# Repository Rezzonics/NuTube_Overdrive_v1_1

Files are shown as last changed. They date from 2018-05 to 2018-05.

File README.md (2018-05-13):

# NuTube_Overdrive_v1_1 (EAGLE 6.3.0)
NuTube Overdrive guitar pedal

Eagle CAD 6.3.0:
- Eagle CAD Schematics (.sch)
- Eagle CAD Layout (.brd)
- Bill of Materials (txt, csv, xlsx)
- Components library (.lbr)

FreeCAD 16.0:
 - 3D CAD NuTube Overdrive enclosure
 
A <a href="https://www.youtube.com/watch?v=pDtBdqI9vC8&list=PLVcOAdxtwYCBdqzgB6T4JSNhljZ__4p3t">guitar pedal test video Youtube playlist<a>

# Disclaimer:
This is just an amateur pedal with no intention for profit or to infringe any trademark.
Tube Screamer is a trademark of Hoshino Gakki Co.
This pedal is not for sale. If you want to buy a similar pedal I recommend you <a href="http://www.ibanez.com/products/u_effect_page18.php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">Ibanez NTS Screamer<a>

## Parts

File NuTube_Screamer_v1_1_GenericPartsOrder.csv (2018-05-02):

Part Number | Mfg Name | VID | Vendor Part Num | Description | Customer Ref | Part Value | Tol | Size | Qty-1 | Qty-5 | Qty-25 | Part References | Value | XX
CRCW06030000ZSTB | Vishay | ME | 71-CRCW0603000ZT-RT5 | Thick Film Resistors - SMD 0603 1/10watt ZEROohm Jumper | res013 | 0 | * | * | 2 | 10 | 50 | R13, R14 | 0R | X
ERJ-3EKF1001V | Panasonic | ME | 667-ERJ-3EKF1001V | Thick Film Resistors - SMD 0603 1Kohms 1% Tol | res018 | 1k | * | * | 7 | 35 | 175 | R5, R9, R16, R23, R25, R27, R33 | 1K | X
CR0603-FX-1004ELF | Bourns | ME | 652-CR0603FX-1004ELF | Thick Film Resistors - SMD 0603 1M 1% 1/10W | res003 | 1M | * | * | 7 | 35 | 175 | R3, R7, R8, R11, R24, R26, R31 | 1M | X
C1608X7R1V105K080AE | TDK | ME | 810-C1608X7R1V105KAE | CAP CER 1UF 35V 10% X7R 0603 | capcer067 | 1u | 10% | * | 8 | 40 | 200 | C3, C4, C5, C6, C7, C18, C19, C23 | 1u | X
RC0603FR-073K3L | Yageo | ME | 603-RC0603FR-073K3L | Thick Film Resistors - SMD 0603 3.3kohms 1% Tol | res139 | 3.3k | * | * | 1 | 5 | 25 | R28 | 3.3k | X
ERJ-3EKF4701V | Panasonic | ME | 667-ERJ-3EKF4701V | Thick Film Resistors - SMD 0603 4.7Kohms 1% Tol | res027 | 4.7k | * | * | 1 | 5 | 25 | R15 | 4.7k | X
C2012X5R1E475K125AB | TDK | ME | 810-C2012X5R1E475K | CAP CER 4.7uF 25volts X5R 10% 0805 | capcer006 | 4.7u | 10% | * | 2 | 10 | 50 | C21, C31 | 4.7u | X
ERJ-3EKF4701V | Panasonic | ME | 667-ERJ-3EKF4701V | Thick Film Resistors - SMD 0603 4.7Kohms 1% Tol | res027 | 4.7k | * | * | 1 | 5 | 25 | R35 | 4k7 | X
CR0603-FX-1002HLF | Bourns | ME | 652-CR0603-FX1002HLF | Thick Film Resistors - SMD 0603 10KOHM 1/10WATT 1% | res002 | 10k | * | * | 6 | 30 | 150 | R1, R2, R10, R12, R22, R32 | 10k | X
GRM21BR6YA106KE43L | Murata | ME | 81-GRM21BR6YA106KE3L | CAP CER 10UF 35V X5R 0805 | capcer075 | 10u | * | 805 | 15 | 75 | 375 | C1, C2, C10, C12, C13, C14, C15, C16, C17, C20, C24, C25, C26, C30, C33 | 10u | X
SRN4018-100M | Bourns | ME | 652-SRN4018-100M | FIXED IND 10UH 1.3A 180 MOHM SMD | ind010 | 10u | * | * | 1 | 5 | 25 | L1 | 10u | X
C2012X5R1V226M125AC | TDK | ME | 810-C2012X5R1V226MAC | CAP CER 22UF 35V X5R 0805 | capcer078 | 22u | * | * | 1 | 5 | 25 | C32 | 22u | X
CR0603-FX-3302ELF | Bourns | ME | 652-CR0603FX-3302ELF | Thick Film Resistors - SMD 0603 33K ohm 1% | res008 | 33k | * | * | 2 | 10 | 50 | R17, R18 | 33k | X
06035D473MAT2A | AVX | ME | 581-06035D473MAT2A | CAP CER 0.047UF 50V X5R 0603 | capcer086 | 47n | 20% | 603 | 2 | 10 | 50 | C9, C29 | 47n | X
GCM1885C2A470JA16D | Murata | ME | 81-GCM1885C2A470J16D | CAP CER 47PF 100V C0G/NP0 0603 | capcer087 | 47p | 5% | 603 | 1 | 5 | 25 | C11 | 47p | X
ERJ-3EKF5102V | Panasonic | ME | 667-ERJ-3EKF5102V | Thick Film Resistors - SMD 0603 51Kohms 1% Tol | res046 | 51k | * | * | 1 | 5 | 25 | R19 | 51k | X
RC0603FR-0768KL | Yageo | ME | 603-RC0603FR-0768KL | Thick Film Resistors - SMD 0603 68kohms 1% Tol | res138 | 68k | * | * | 1 | 5 | 25 | R34 | 68k | X
ERJ-3EKF8202V | Panasonic | ME | 667-ERJ-3EKF8202V | RES SMD 82K OHM 1% 1/10W 0603 | res042 | 82k | * | * | 1 | 5 | 25 | R41 | 82k | X
RC0603FR-07100RL | Yageo | ME | 603-RC0603FR-07100RL | RES SMD 100 OHM 1% 1/10W 0603 | res131 | 100 | * | * | 1 | 5 | 25 | R29 | 100 | X
ERJ-3EKF1003V | Panasonic | ME | 667-ERJ-3EKF1003V | RES SMD 100K OHM 1% 1/10W 0603 | res048 | 100k | * | * | 2 | 10 | 50 | R6, R40 | 100k | X
EEE-1VA101XP | Panasonic | ME | 667-EEE-1VA101XP | CAP ALUM 100UF 20% 35V SMD | capelec002 | 100u | * | * | 1 | 5 | 25 | C22 | 100u | X
RC0603FR-07180KL | Yageo | ME | 603-RC0603FR-07180KL | Thick Film Resistors - SMD 0603 180K 1% 1/10W | res006 | 180k | * | * | 1 | 5 | 25 | R36 | 180k | X
ERJ-PA3F2200V | Panasonic | ME | 667-ERJ-PA3F2200V | RES SMD 220 OHM 1% 1/4W 0603 | res132 | 220 | * | * | 2 | 10 | 50 | R30, R37 | 220 | X
GRM188R61H224KAC4D | Murata | ME | 81-GRM188R61H224KACD | CAP CER 0.22UF 50V X5R 0603 | capcer088 | 220n | 10% | 603 | 3 | 15 | 75 | C8, C27, C28 | 220n | X
ERJ-3EKF2400V | Panasonic | ME | 667-ERJ-3EKF2400V | RES SMD 240 OHM 1% 1/10W 0603 | res121 | 240 | * | * | 2 | 10 | 50 | R20, R21 | 240 | X
CR0603-FX-4303ELF | Bourns | ME | 652-CR0603FX-4303ELF | Thick Film Resistors - SMD 0603 430K ohm 1% | res010 | 430k | * | * | 1 | 5 | 25 | R39 | 430k | X
CR0603-FX-5103ELF | Bourns | ME | 652-CR0603FX-5103ELF | Thick Film Resistors - SMD 0603 510kohms 1% Tol | res140 | 510k | 1% | 603 | 1 | 5 | 25 | R4 | 510k | X
PTV09A-4020S-A104 | Bourns | ME | 652-PTV09A4020SA104 | Potentiometers 9mm 100Kohms Audio | pot024 | A100K | * | * | 1 | 5 | 25 | VOL | A100K | X
PTV09A-4020F-B502 | Bourns | ME | 652-PTV09A-4020FB502 | Potentiometers 9mm 5Kohms Linear | pot023 | B5K | * | * | 1 | 5 | 25 | TONE | B5K | X
3314G-2-103E | Bourns | ME | 652-3314G-2-103E | TRIMMER 10K OHM 0.25W SMD | pottrim005 | B10k | * | * | 1 | 5 | 25 | RV1 | B10k | X
PTV09A-4020S-B104 | Bourns | ME | 652-PTV09A4020SB104 | Potentiometers 9mm 100Kohms Linear | pot025 | B100K | * | * | 1 | 5 | 25 | MIX | B100K | X
PTV09A-4020S-B504 | Bourns | ME | 652-PTV09A4020SB504 | Potentiometers 9mm 500Kohms Linear | pot026 | B500K | * | * | 1 | 5 | 25 | GAIN | B500K | X
3314G-1-504E | Bourns | ME | 652-3314G-1-504E | TRIMMER 500K OHM 0.25W SMD | pottrim003 | B500k | * | * | 2 | 10 | 50 | VR1, VR2 | B500k | X
BAV199235 | NXP | ME | 771-BAV199235 | Rectifiers DIODE LOW LEAKAGE | diode002 | BAV199 | * | * | 2 | 10 | 50 | D1, D2 | BAV199 | X
BLM31PG121SN1L | Murata | ME | 81-BLM31PG121SN1L | EMI Filter Beads Chips & Arrays 1206 120 OHM | fer002 | 120 | * | * | 2 | 10 | 50 | FB1, FB2 | BLM31PG121SN1L | X
591 | Keystone electronics | ME | 534-591 | Cylindrical Battery Contacts Clips Holders & Springs AA/AAA SPRING CONT | con025 | 591 | * | * | 1 | 5 | 25 | X1 | CLIPAAA-CLIPAAA_2 | X
PJ-202A | CUI | ME | 490-PJ-202A | CONN POWER JACK 2.1MM PCB | con014 | PJ-202A | * | * | 1 | 5 | 25 | J2 | DCJ0202 | X
SSL-LX5093GD | Lumex | ME | 696-SSL-LX5093GD | LED GRN DIFF 5MM ROUND T/H | led010 | Green | * | * | 1 | 5 | 25 | LED1 | GREEN | X
NMJ4HCD2 | REAN | ME | 550-12202 | Phone Connectors 2C MONO 2-SPST NC | con005 | * | * | * | 1 | 5 | 25 | J1 | INPUT | X
LM4041CIDBZR | Texas Instruments | ME | 595-LM4041CIDBZR | Voltage References Adjustable Precision Mcrpwr Shunt .5% | vref002 | LM4041CIDBZR | * | * | 1 | 5 | 25 | U4 | LM4041CIDBZ | X
LME49723MA/NOPB | Texas Instruments | ME | 926-LME49723MA/NOPB | Audio Amplifiers Dual Audio Op Amp | icopamp002 | LME49723 | * | * | 2 | 10 | 50 | U1, U3 | LME49723 | X
MBR0520LT1G | ON Semiconductor | ME | 863-MBR0520LT1G | Schottky Diodes & Rectifiers 0.5A 20V | diodes006 | MBR0520 | * | * | 1 | 5 | 25 | D3 | MBR0520LT1G | X
MMBT5089 | Fairchild Semiconductor | ME | 512-MMBT5089 | Transistors Bipolar - BJT NPN Transistor General Purpose | bjt001 | MMBT5089 | * | * | 3 | 15 | 75 | T1, T2, T3 | MMBT5089 | X
NFM3DPC223R1H3L | Murata | ME | 81-NFM3DPC223R1H3L | EMI/RFI Suppressors & Ferrites 0.022uF 50V 2A' | fer001 | 22n | * | * | 1 | 5 | 25 | CF1 | NFM3DC | X
831-87-032-10-001101 | APEM Inc. | ME | 437-8318703210001101 | Conn SIP Socket Strip SKT 32 POS 2mm Solder ST Thru-Hole | con024 | 831-87-032-10-001101 | * | * | 1 | 5 | 25 | U2 | NUTUBE 6P1 | X
NMJ4HCD2 | REAN | ME | 550-12202 | Phone Connectors 2C MONO 2-SPST NC | con005 | * | * | * | 1 | 5 | 25 | J3 | OUTPUT | X
TPS62175DQCR | Texas Instruments | ME | 595-TPS62175DQCR | IC REG BUCK BST ADJ 0.5A 10WSON | icreg009 | TPS62175 | * | * | 1 | 5 | 25 | U5 | TPS62175DQCR | X
1249 | Keystone electronics | ME | 534-1249 | Test Points TP TERM BRS MATTE TINNED PLATED | tp001 | * | * | * | 5 | 25 | 125 | TP1, TP2, TP3, TP4, TP5 | TPTP10R | X
MHS122K | APEM Inc. | ME | 642-MHS122K | SWITCH SLIDE SPDT 300MA 30V | sw0013 | MHS122K | * | * | 1 | 5 | 25 | S1 | clip | X

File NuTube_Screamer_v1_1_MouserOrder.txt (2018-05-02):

71-CRCW0603000ZT-RT5|2
667-ERJ-3EKF1001V|7
652-CR0603FX-1004ELF|7
810-C1608X7R1V105KAE|8
603-RC0603FR-073K3L|1
667-ERJ-3EKF4701V|1
810-C2012X5R1E475K|2
667-ERJ-3EKF4701V|1
652-CR0603-FX1002HLF|6
81-GRM21BR6YA106KE3L|15
652-SRN4018-100M|1
810-C2012X5R1V226MAC|1
652-CR0603FX-3302ELF|2
581-06035D473MAT2A|2
81-GCM1885C2A470J16D|1
667-ERJ-3EKF5102V|1
603-RC0603FR-0768KL|1
667-ERJ-3EKF8202V|1
603-RC0603FR-07100RL|1
667-ERJ-3EKF1003V|2
667-EEE-1VA101XP|1
603-RC0603FR-07180KL|1
667-ERJ-PA3F2200V|2
81-GRM188R61H224KACD|3
667-ERJ-3EKF2400V|2
652-CR0603FX-4303ELF|1
652-CR0603FX-5103ELF|1
652-PTV09A4020SA104|1
652-PTV09A-4020FB502|1
652-3314G-2-103E|1
652-PTV09A4020SB104|1
652-PTV09A4020SB504|1
652-3314G-1-504E|2
*|1 *** ERROR : JP1
771-BAV199235|2
81-BLM31PG121SN1L|2
534-591|1
490-PJ-202A|1
*|1 *** ERROR : JP2
696-SSL-LX5093GD|1
550-12202|1
595-LM4041CIDBZR|1
926-LME49723MA/NOPB|2
863-MBR0520LT1G|1
512-MMBT5089|3
81-NFM3DPC223R1H3L|1
437-8318703210001101|1
550-12202|1
595-TPS62175DQCR|1
534-1249|5
642-MHS122K|1

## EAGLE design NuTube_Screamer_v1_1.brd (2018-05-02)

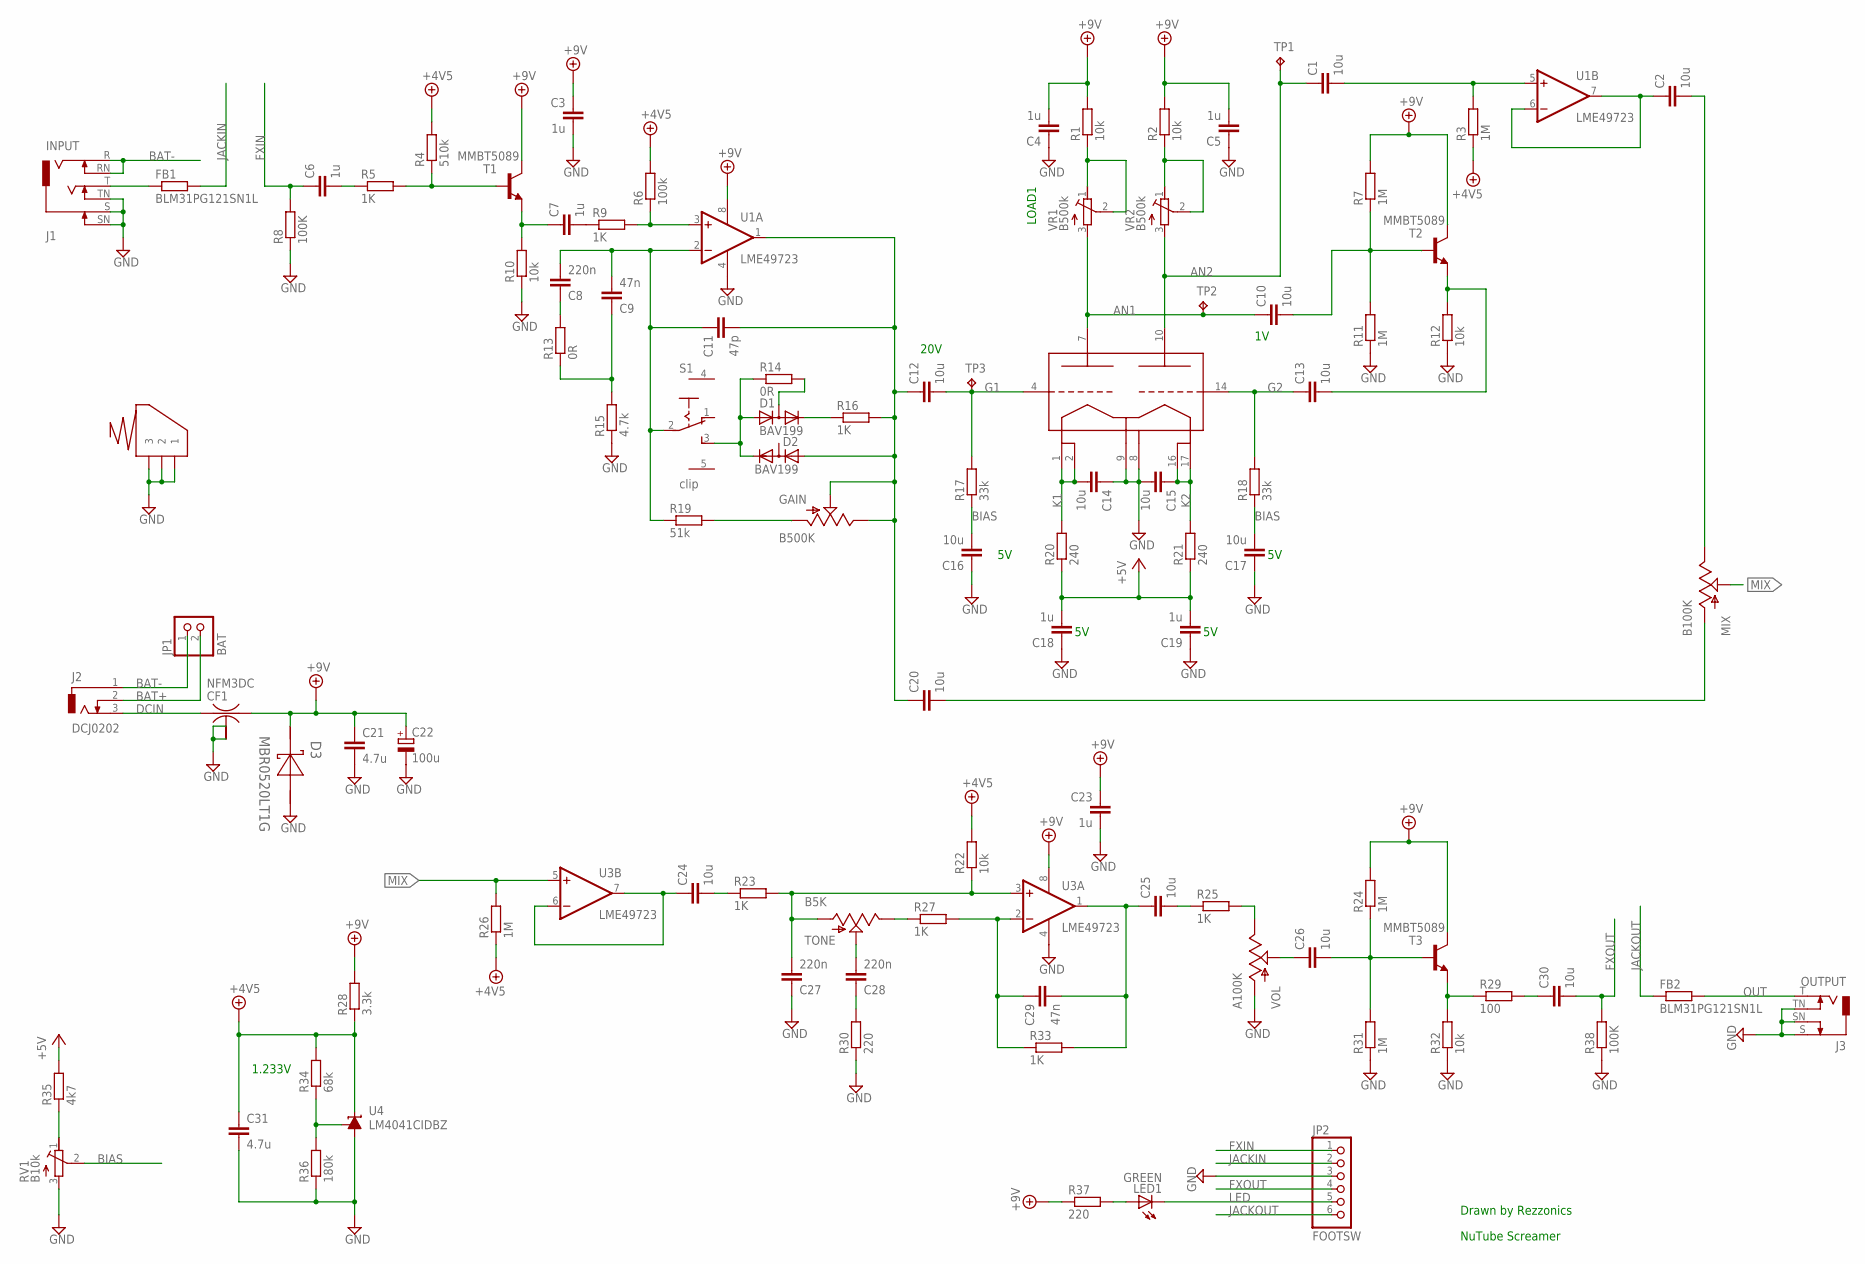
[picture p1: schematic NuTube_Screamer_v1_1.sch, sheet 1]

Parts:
C1, C2, C10, C12, C14, C15, C16, C17, C20, C24, C25, C26, C30: 10u; C0805K; MPN GRM21BR6YA106KE43L
C3, C6, C7, C23: 1u; C0603K; MPN GRM188R71H104KA93D
C4, C5, C18, C19: 1u; C0603K; MPN C1608X5R1H105K080AB
C8, C27, C28: 220n; C0603K; MPN GRM188R71H104KA93D
C9, C29: 47n; C0603K; MPN GRM188R71H104KA93D
C11: 47p; C0603K; MPN GRM188R71H104KA93D
C13: 10u; C0805K; PARTNO GRM21BR6YA106KE43L
C21, C31: 4.7u; C0805K; MPN GRM21BR61E475KA12L
C22: 100u; PANASONIC_D; MPN EEE-1VA101XP
CF1: NFM3DC; MPN NFM3DPC223R1H3L
D1, D2: BAV199; SOT23; PARTNO BAV199235
D3: MBR0520LT1G; SOD-123; MPN MBR0520LT1G
FB1, FB2: BLM31PG121SN1L; R1206; MPN BLM31PG121SN1L
GAIN: B500K; ALPS_POT; PARTNO PTV09A-4020S-B504
J1: INPUT; NEUTRIK-NMJ6HCD2; MPN NMJ6HCD2
J2: DCJ0202; MPN 163-179PH-EX
J3: OUTPUT; NEUTRIK-NMJ4HCD2; MPN NMJ4HCD2
JP1: BAT; 1X02; MPN *
JP2: FOOTSW; 1X06; MPN *
LED1: GREEN; LED5MM; MPN SSL-LX5093GD
MIX: B100K; ALPS_POT; PARTNO PTV09A-4020S-B104
R1, R2: 10k; R0603; MPN ERJ-2RKF1002X
R3, R7, R11, R24, R26, R31: 1M; R0603@1; MPN CR0603-FX-1004ELF
R4: 510k; R0603@1; MPN CR0603-FX-1004ELF
R5, R9, R16, R23, R25, R27, R33: 1K; R0603@1; MPN CR0603-FX-1002HLF
R6: 100k; R0603@1; MPN CR0603-FX-1004ELF
R8, R38: 100K; R0603@1; MPN CR0603-FX-1004ELF
R10, R12, R22, R32: 10k; R0603@1; MPN CR0603-FX-1004ELF
R13, R14: 0R; R0603@1; MPN CR0603-FX-1002HLF
R15: 4.7k; R0603@1; MPN CR0603-FX-1004ELF
R17, R18: 33k; R0603; MPN ERJ-2RKF3302X
R19: 51k; R0603@1; MPN CR0603-FX-1002HLF
R20, R21: 240; R0603; MPN ERJ-3EKF2400V
R28: 3.3k; R0603@1; MPN RC0603FR-073K3L
R29: 100; R0603@1; MPN CR0603-FX-1002HLF
R30: 220; R0603@1; MPN CR0603-FX-1004ELF
R34: 68k; R0603@1; MPN RC0603FR-0768KL
R35: 4k7; R0603; MPN ERJ-2RKF4701X
R36: 180k; R0603@1; MPN RC0603FR-07180KL
R37: 220; R0603@1; MPN ERJ-PA3F2200V
RV1: B10k; RTRIM3314G; MPN 3314G-2-103E
S1: clip; MHS122K; PARTNO MHS122K
T1, T2, T3: MMBT5089; SOT23-BEC; PARTNO MMBT5089
TONE: B5K; ALPS_POT; PARTNO PTV09A-4020F-B502
TP1, TP2, TP3: TPTP10R; TP10R; MPN *
U1, U3: LME49723; SO08; MPN LME49723MA/NOPB
U2: NUTUBE 6P1; NUTUBE_6P1_1; MPN *
U4: LM4041CIDBZ; DBZ_R-PDSO-G3; MPN LM4041CIDBZR
VOL: A100K; ALPS_POT; PARTNO PTV09A-4020S-A104
VR1, VR2: B500k; RTRIM3314G; MPN 3314G-1-504E
X1: CLIPAAA-CLIPAAA_2; CLIPAAA_2; MPN 591

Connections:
+4.5V: C31.1, R3.1, R4.2, R6.2, R22.2, R26.1, R28.1, R34.2, U4.2 (C)
+5V: C18.2, C19.2, R20.1, R21.1, R35.2; also elsewhere on the board
+9V: C3.1, C4.2, C5.2, C21.1, C22.+, C23.1, CF1.3, D3.1 (K), R1.2, R2.2, R7.2, R24.2, R28.2, R37.1, T1.C, T2.C, T3.C, U1.8 (V+), U3.8 (V+); also elsewhere on the board
AN1: C10.1, TP2.TP, U2.7 (A1_7), VR1.3 (A)
AN2: C1.1, TP1.TP, U2.10 (A2_10), VR2.3 (A)
BAT+: J2.2, JP1.2
BAT-: J1.R, J1.RN, J2.1, JP1.1
BIAS: C16.2, C17.2, R17.1, R18.1, RV1.2 (S)
DCIN: CF1.1, J2.3
FXIN: C6.1, JP2.1, R8.2
FXOUT: C30.2, JP2.4, R38.2
G1: C12.2, R17.2, TP3.TP, U2.4 (G1_4)
G2: C13.1, R18.2, U2.14 (G2_14)
GND: C3.2, C4.1, C5.1, C14.1, C15.2, C16.1, C17.1, C18.1, C19.1, C21.2, C22.-, C23.2, C27.1, C31.2, CF1.2@1 (2), CF1.2@2 (2), D3.2 (A), J1.S, J1.SN, J1.TN, J3.S, J3.SN, J3.TN, JP2.3, R8.1, R10.1, R11.1, R12.1, R15.1, R30.1, R31.1, R32.1, R36.1, R38.1, RV1.3 (A), U1.4 (V-), U2.8 (GND_8), U2.9 (F2_9), U3.4 (V-), U4.3 (A), VOL.P$1 (A), X1.1, X1.2, X1.3; also elsewhere on the board
JACKIN: FB1.2, JP2.2
JACKOUT: FB2.1, JP2.6
K1: C14.2, R20.2, U2.1 (F1_1), U2.2 (F1_2)
K2: C15.1, R21.2, U2.16 (F3_16), U2.17 (F3_17)
LED: JP2.5, LED1.K (C)
MIX: MIX.P$2 (S), R26.2, U3.5 (+IN)
unnamed: C10.2, R7.1, R11.2, T2.B
unnamed: C6.2, R5.1
unnamed: C13.2, R12.2, T2.E
unnamed: FB1.1, J1.T
unnamed: C7.1, R10.2, T1.E
unnamed: R4.1, R5.2, T1.B
unnamed: C7.2, R9.1
unnamed: R6.1, R9.2, U1.3 (+IN)
unnamed: D1.2 (C), R16.1
unnamed: D1.1 (A), D2.2 (C), R14.1, S1.3 (S)
unnamed: D1.3 (AC), R14.2
unnamed: C11.2, C12.1, C20.1, D2.1 (A), GAIN.P$2 (S), GAIN.P$3 (E), R16.2, U1.1 (OUT)
unnamed: C8.2, C9.2, C11.1, R19.1, S1.2, U1.2 (-IN)
unnamed: GAIN.P$1 (A), R19.2
unnamed: R34.1, R36.2, U4.1 (FB)
unnamed: LED1.A, R37.2
unnamed: C8.1, R13.2
unnamed: R35.1, RV1.1 (E)
unnamed: C9.1, R13.1, R15.2
unnamed: C1.2, R3.2, U1.5 (+IN)
unnamed: C2.1, U1.6 (-IN), U1.7 (OUT)
unnamed: C20.2, MIX.P$1 (A)
unnamed: C2.2, MIX.P$3 (E)
unnamed: C27.2, R22.1, R23.2, TONE.P$1 (A), U3.3 (+IN)
unnamed: C24.1, U3.6 (-IN), U3.7 (OUT)
unnamed: C24.2, R23.1
unnamed: C25.1, C29.2, R33.2, U3.1 (OUT)
unnamed: R27.1, TONE.P$3 (E)
unnamed: C28.2, TONE.P$2 (S)
unnamed: C28.1, R30.2
unnamed: C29.1, R27.2, R33.1, U3.2 (-IN)
unnamed: C25.2, R25.1
unnamed: R25.2, VOL.P$3 (E)
unnamed: C26.1, VOL.P$2 (S)
unnamed: C26.2, R24.1, R31.2, T3.B
unnamed: R29.1, R32.2, T3.E
unnamed: C30.1, R29.2
OUT: FB2.2, J3.T
RL1: R1.1, VR1.1 (E), VR1.2 (S)
RL2: R2.1, VR2.1 (E), VR2.2 (S)

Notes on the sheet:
Drawn by Rezzonics
NuTube Screamer
20V
LOAD1
1.233V

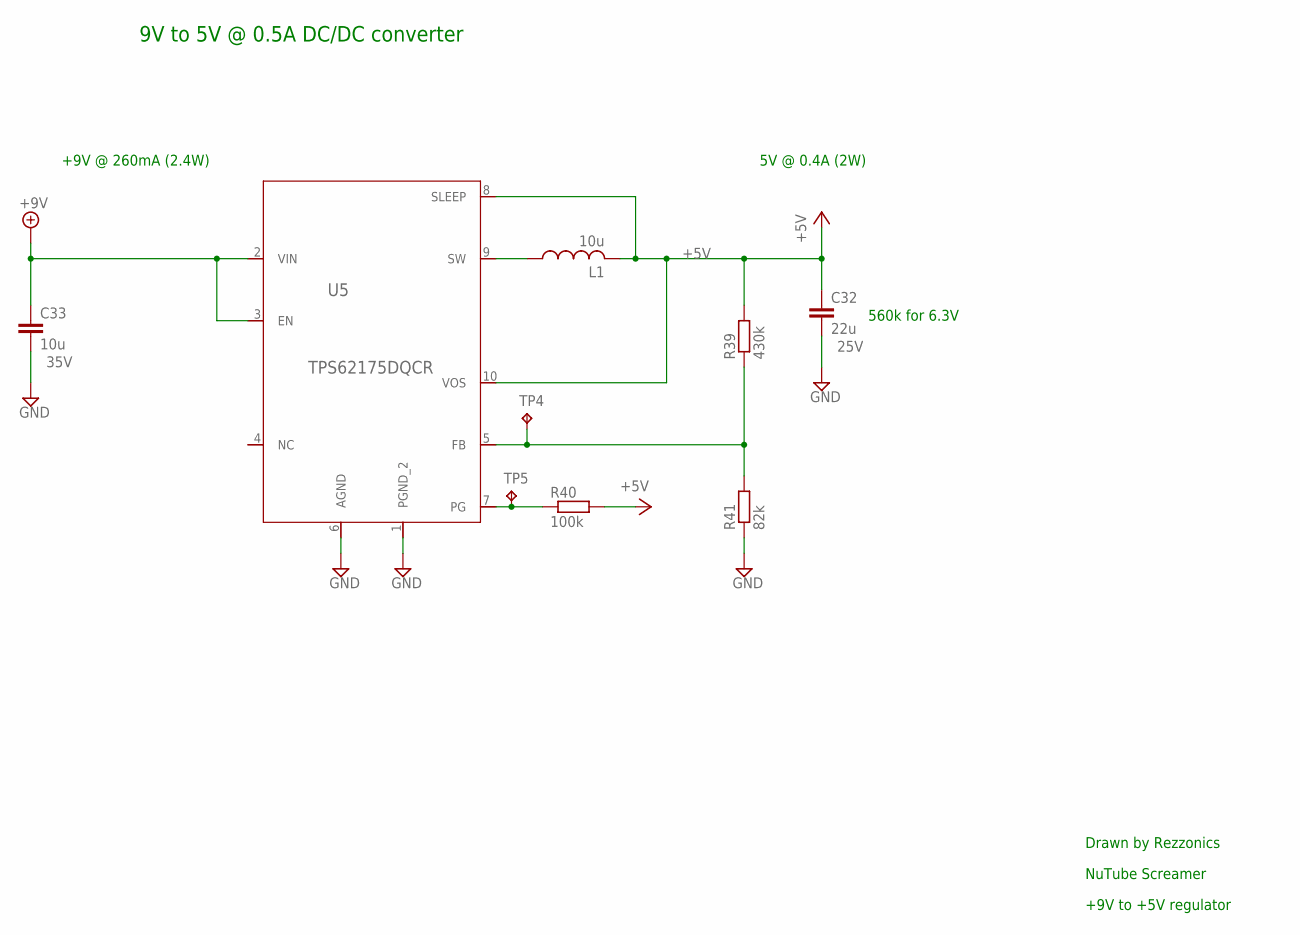
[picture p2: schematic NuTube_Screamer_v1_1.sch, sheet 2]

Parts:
C32: 22u; C0805K; MPN C2012X5R1V226M125AC
C33: 10u; C0805K; MPN GRM21BR6YA106KE43L
L1: 10u; SRN4018; MPN SRN4018-100M
R39: 430k; R0603; MPN ERJ-2GEJ434X
R40: 100k; R0603; MPN ERJ-2RKF1003X
R41: 82k; R0603; MPN ERJ-2RKF8202X
TP4, TP5: TPTP10R; TP10R; MPN *
U5: TPS62175DQCR; R-PWSON-N10; MPN TPS62175DQCR

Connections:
+5V: C32.1, L1.2, R39.2, R40.2, U5.8 (SLEEP), U5.10 (VOS); also elsewhere on the board
+9V: C33.1, U5.2 (VIN), U5.3 (EN); also elsewhere on the board
GND: C32.2, C33.2, R41.1, U5.1 (PGND_2), U5.6 (AGND); also elsewhere on the board
unnamed: R40.1, TP5.TP, U5.7 (PG)
unnamed: L1.1, U5.9 (SW)
VCC3: R39.1, R41.2, TP4.TP, U5.5 (FB)

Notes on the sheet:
+9V @ 260mA (2.4W)
9V to 5V @ 0.5A DC/DC converter
5V @ 0.4A (2W)
560k for 6.3V
Drawn by Rezzonics
NuTube Screamer
+9V to +5V regulator

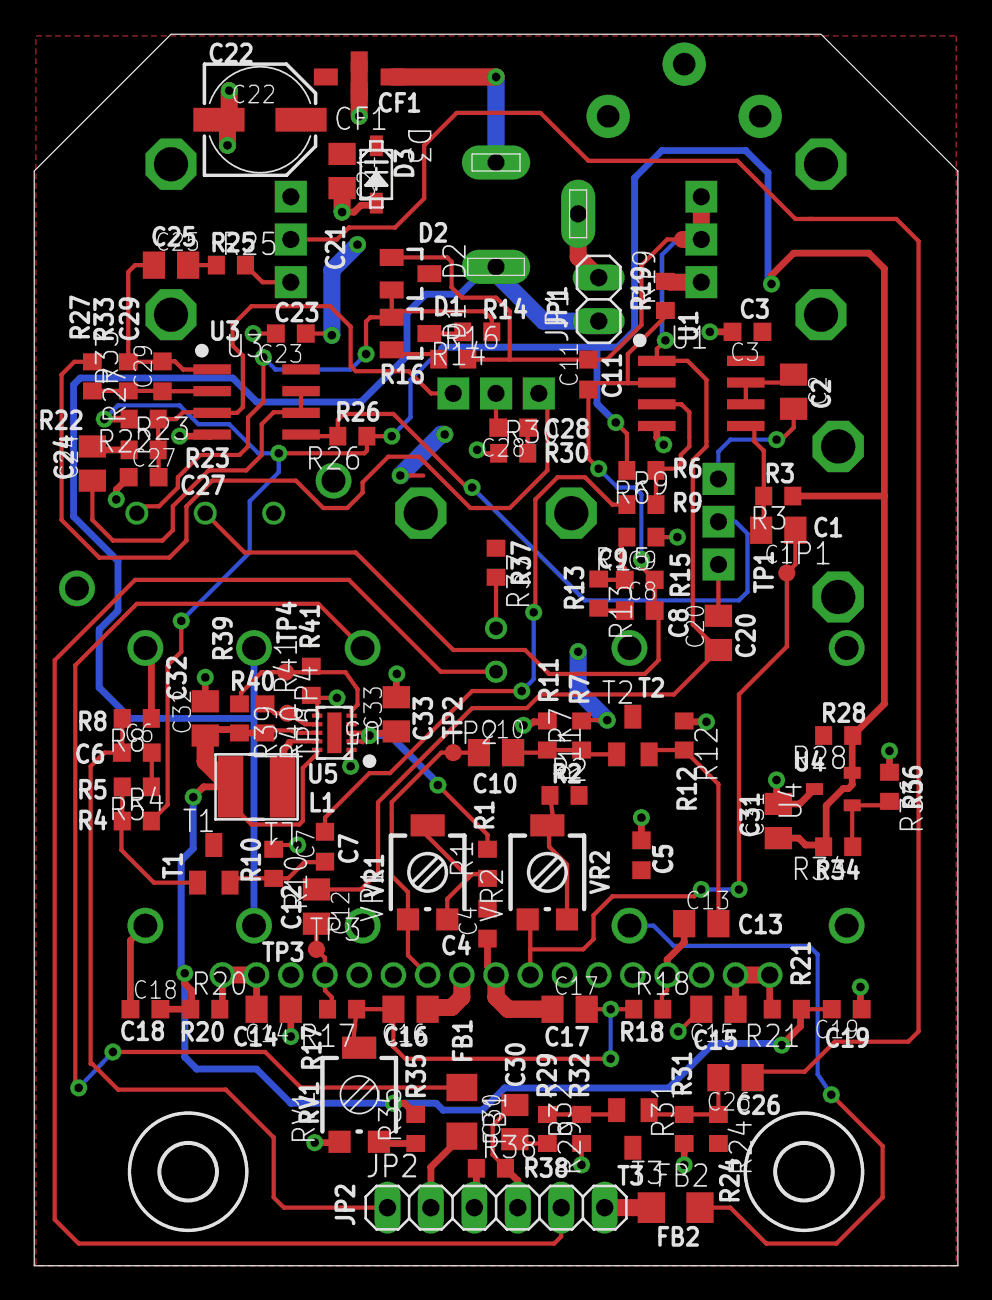
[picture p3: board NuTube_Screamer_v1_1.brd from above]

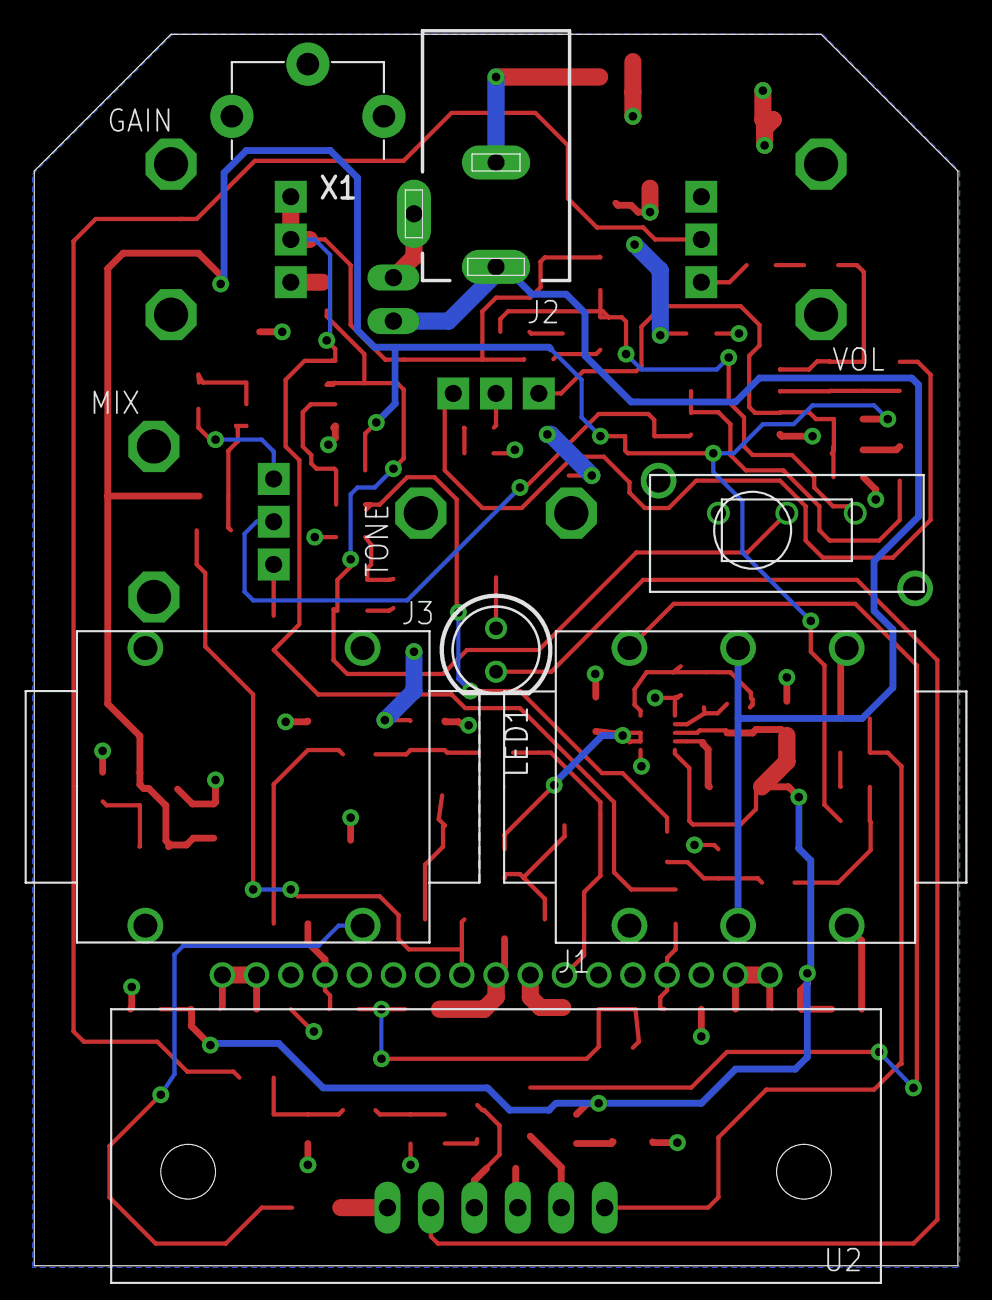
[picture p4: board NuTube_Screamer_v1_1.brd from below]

Board: 2 copper layers, 54.0 x 72.0 mm, 111 parts (11 on the bottom side), 63 nets.

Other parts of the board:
U$1, U$2: 3,2
